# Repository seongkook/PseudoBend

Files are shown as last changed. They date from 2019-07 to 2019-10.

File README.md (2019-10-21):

# PseudoBend

PseudoBend paper is available at here: https://dl.acm.org/citation.cfm?id=3347941

See Video Preview: https://www.youtube.com/watch?v=w7GSAcuDjo4&feature=youtu.be

PseudoBend is a haptic feedback technique that uses grain vibrations to create illusions of stretching, bending, and twisting on a rigid device. Details of PseudoBend will be publised as a paper at ACM UIST 2019.

This repository contains resources required to replicate PseudoBend, including 3D models to print handles, schematic and firmware for signal generation circuit, and PseudoBend software.  

To build the system, you may need the following parts, in addition to the 3D-printed handles. These are the parts used in the implementation in the paper, but you can use alternate parts with similar characteristics.

* Sensor: ATI Nano25 6-DOF Force/Torque Sensor (https://www.ati-ia.com/products/ft/ft_models.aspx?id=Nano25)
* Micro Controller: Teensy 3.6 (https://www.sparkfun.com/products/14057)
* Actuator: Haptuator BM2C (http://tactilelabs.com/wp-content/uploads/2016/06/Haptuator-BMXC-series-v1.1.pdf)
* Amplifier: TDA7297 Audio Amplifier (https://www.amazon.com/DROK-TDA7297-15W-Amplifier-Component/dp/B00C4MT274)

The complete device looks like the picture below, with a force/torque sensor installed in between the two handles.
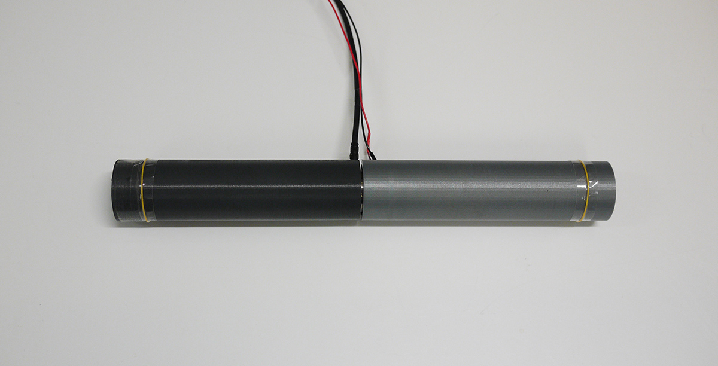
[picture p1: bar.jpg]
Device Image


Nano25 sensor connects the two handles. Three M3 screws connects each handle and the sensor.  
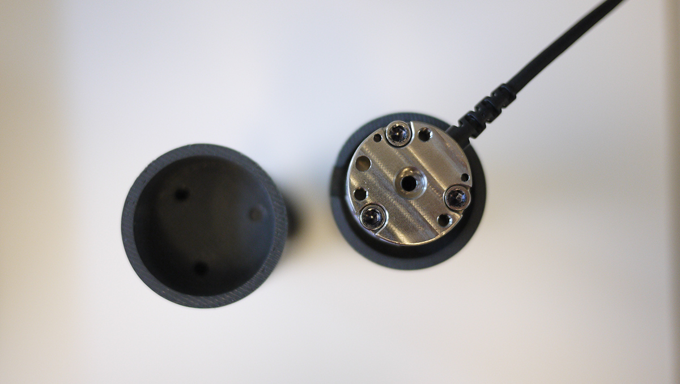
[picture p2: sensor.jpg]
Sensor Image


Teensy 3.6 board generates the vibration signal using its DAC pin. TDA7297 amplifies the signal generated by the Teensy board.  
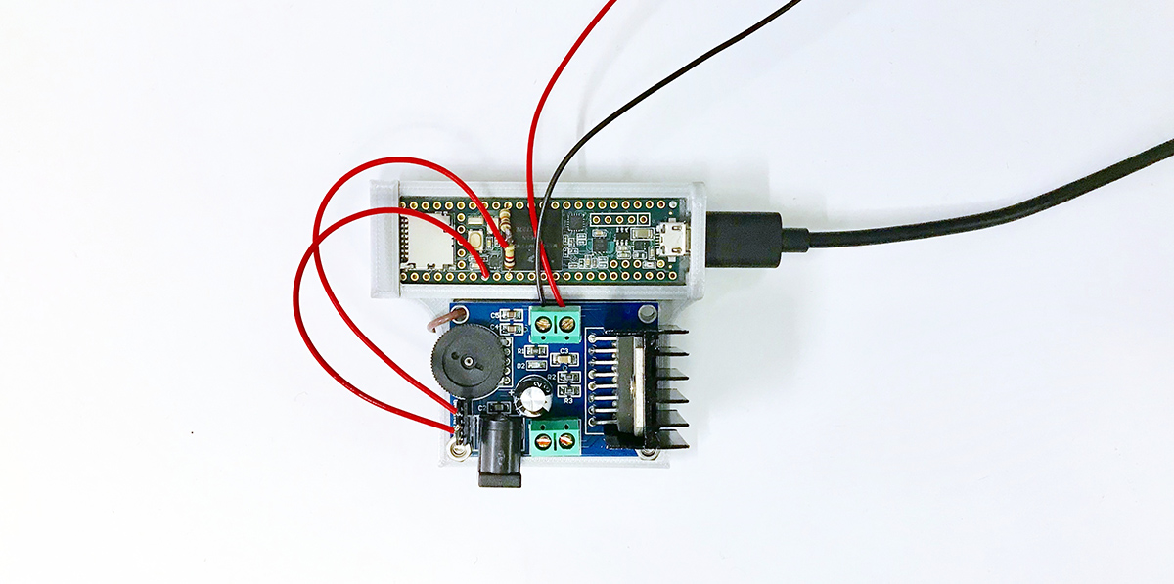
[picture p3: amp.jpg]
Amplifier Image


If you have any questions, please send an email to seongkook@virginia.edu

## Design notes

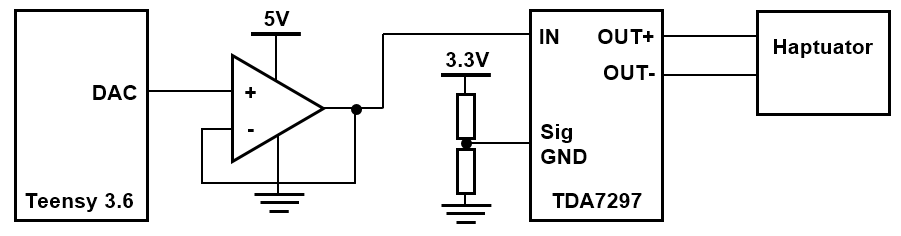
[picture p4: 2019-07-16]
Signal Generator/Circuit Diagram/Drive Circuit.PNG

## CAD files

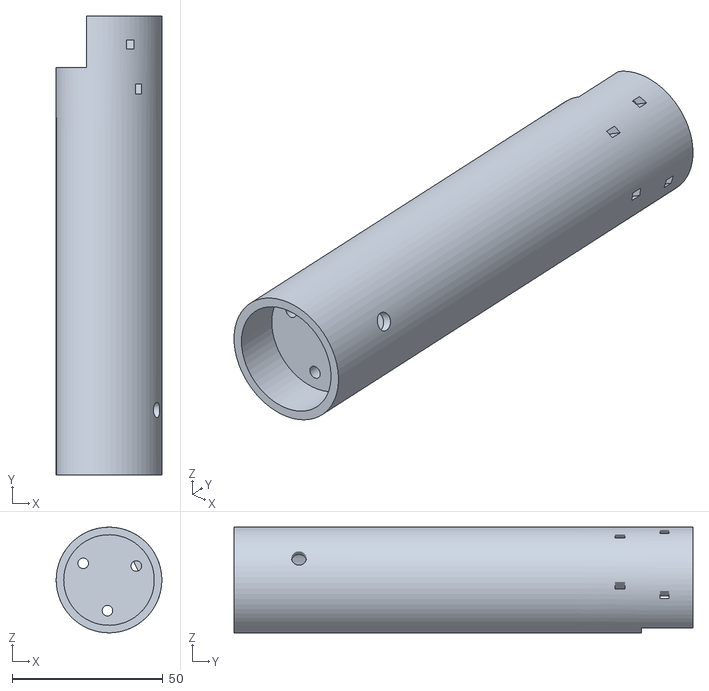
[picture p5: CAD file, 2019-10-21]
3D models/Handle_ActuatorSide_EasyAccess.stl
35.0 x 152.0 x 35.0

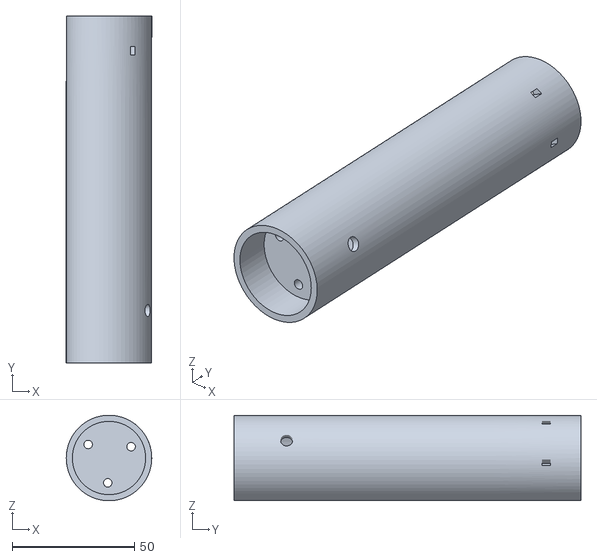
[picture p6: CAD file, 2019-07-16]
3D models/Handle_ActuatorSide.stl
35.0 x 142.0 x 35.0

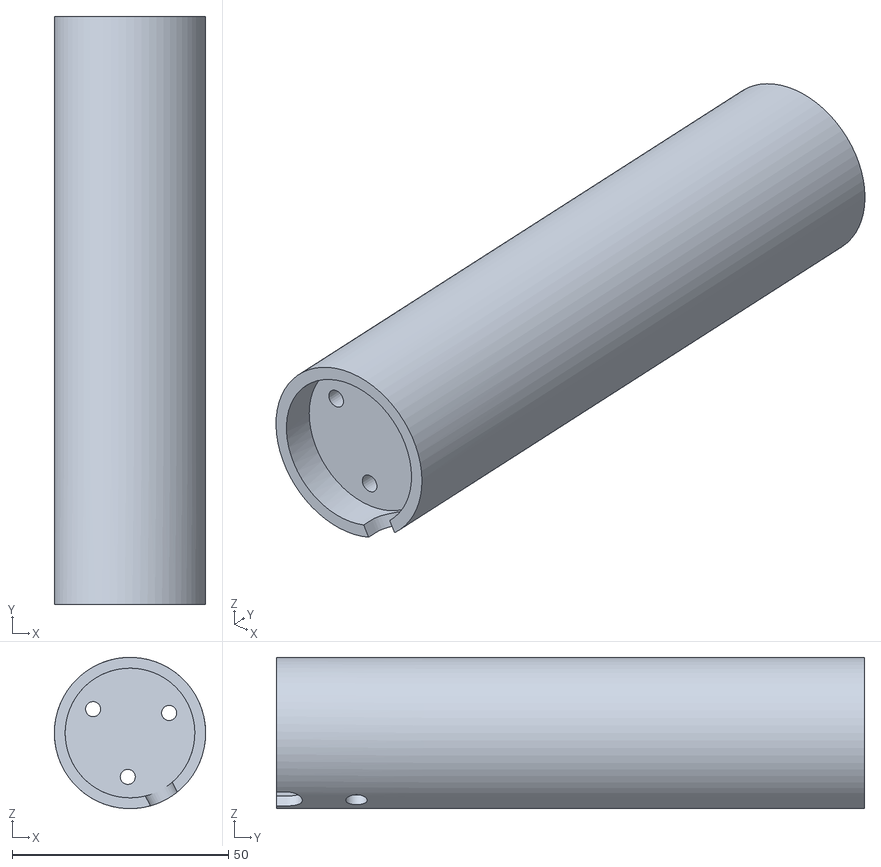
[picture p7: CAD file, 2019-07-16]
3D models/Handle_SensorSide.stl
35.0 x 136.0 x 35.0

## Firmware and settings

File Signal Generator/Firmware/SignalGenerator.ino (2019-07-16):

float twopi = 3.14159 * 2;
int sampleInt = 80;
elapsedMicros usec = 0;

float samples[] {0, 0.10394775, 0.205601561, 0.303866711, 0.397698051, 0.486111111, 0.568192411, 0.643108861, 0.710116167, 0.768566145, 0.817912881, 0.85771768, 0.887652749, 0.907503607, 0.917170192, 0.916666667, 0.906119949, 0.885766994, 0.855950865, 0.817115659, 0.769800359, 0.714631678, 0.652316013, 0.583630584, 0.509413885, 0.430555556, 0.347985795, 0.262664445, 0.175569872, 0.087687766, 1.02E-16, -0.086526339, -0.170949612, -0.252363879, -0.32990861, -0.402777778, -0.470228202, -0.531587093, -0.586258696, -0.633729979, -0.673575314, -0.705460103, -0.729143329, -0.744479007, -0.751416543, -0.75, -0.7403663, -0.722742394, -0.697441445, -0.664858083, -0.625462792, -0.579795513, -0.528458543, -0.472108817, -0.411449677, -0.347222222, -0.280196354, -0.211161613, -0.140917924, -0.070266356, -1.63E-16, 0.069104928, 0.136297664, 0.200861046, 0.26211917, 0.319444444, 0.372263993, 0.420065325, 0.462401225, 0.498893813, 0.529237747, 0.553202527, 0.57063391, 0.581454407, 0.585662894, 0.583333333, 0.574612651, 0.559717794, 0.538932026, 0.512600507, 0.481125224, 0.444959347, 0.404601072, 0.360587049, 0.313485468, 0.263888889, 0.212406914, 0.15965878, 0.106265975, 0.052844945, 1.84E-16, -0.051683518, -0.101645716, -0.149358214, -0.194329729, -0.236111111, -0.274299784, -0.308543557, -0.338543754, -0.364057647, -0.384900179, -0.400944951, -0.41212449, -0.418429807, -0.419909245, -0.416666667, -0.408859001, -0.396693194, -0.380422607, -0.360342931, -0.336787657, -0.310123181, -0.280743601, -0.249065281, -0.215521259, -0.180555556, -0.144617473, -0.108155948, -0.071614027, -0.035423535, -1.63E-16, 0.034262107, 0.066993767, 0.097855382, 0.126540289, 0.152777778, 0.176335576, 0.19702179, 0.214686283, 0.229221482, 0.240562612, 0.248687375, 0.253615071, 0.255405207, 0.254155595, 0.25, 0.243105352, 0.233668594, 0.221913187, 0.208085354, 0.19245009, 0.175287015, 0.15688613, 0.137543514, 0.11755705, 0.097222222, 0.076828033, 0.056653116, 0.036962078, 0.018002124, 1.02E-16, -0.016840697, -0.032341819, -0.046352549, -0.058750848, -0.069444444, -0.078371367, -0.085500022, -0.090828812, -0.094385316, -0.096225045, -0.096429798, -0.095105652, -0.092380607, -0.088401946, -0.083333333, -0.077351703, -0.070643993, -0.063403768, -0.055827778, -0.048112522, -0.04045085, -0.033028659, -0.026021746, -0.019592842, -0.013888889, -0.009038592, -0.005150283, -0.00231013, -0.000580714};
float BOsample[] {0, 0.104528463267653, 0.207911690817759, 0.309016994374947, 0.406736643075800, 0.500000000000000, 0.587785252292473, 0.669130606358858, 0.743144825477394, 0.809016994374948, 0.866025403784439, 0.913545457642601, 0.951056516295154, 0.978147600733806, 0.994521895368273, 1, 0.994521895368273, 0.978147600733806, 0.951056516295154, 0.913545457642601, 0.866025403784439, 0.809016994374948, 0.743144825477394, 0.669130606358858, 0.587785252292473, 0.500000000000000, 0.406736643075800, 0.309016994374948, 0.207911690817759, 0.104528463267654, 1.22464679914735e-16, -0.104528463267654, -0.207911690817760, -0.309016994374947, -0.406736643075800, -0.500000000000000, -0.587785252292473, -0.669130606358858, -0.743144825477394, -0.809016994374947, -0.866025403784439, -0.913545457642601, -0.951056516295154, -0.978147600733806, -0.994521895368273, -1, -0.994521895368273, -0.978147600733806, -0.951056516295154, -0.913545457642601, -0.866025403784439, -0.809016994374948, -0.743144825477395, -0.669130606358858, -0.587785252292473, -0.500000000000000, -0.406736643075800, -0.309016994374948, -0.207911690817760, -0.104528463267653, 0};

int phase = 0;
int BO_phase = 0;
boolean play = false;
boolean playBO = false;
int BO_TimeOut = 5000;

int gain = 512;
int offset = 512;

void setup() {
  analogWriteResolution(10);
}

void loop()
{
  if (Serial.available())
  {
    char inChar = (char)Serial.read();
    Serial.println(inChar);
    
    if (inChar == 'a')  // Grain vibration
    {
      usec = 0;
      play = true;
      phase = 0;
    }
    else if (inChar == 'b') // Bottom out
    {
      usec = 0;
      playBO = true;
      phase = 0;
    }
    else if (inChar == 'p')
    {
      gain =  gain + 100;
      Serial.println(gain);
    }
    else if (inChar == 'l')
    {
      gain =  gain - 100;
      Serial.println(gain);
    }
    else if (inChar == 'o')
    {
      offset =  offset + 100;
      Serial.println(offset);
    }
    else if (inChar == 'k')
    {
      offset =  offset - 100;
      Serial.println(offset);
    }
  }
  if (play)
  {
    if (usec > sampleInt)
    {
      analogWrite(A21, (int)(samples[phase] * gain + offset));
      usec = 0;
      if (phase < 180)
      {
        phase ++;
      }
      else
      {
        play = false;
        phase = 0;
      }
    }
  }
  if(playBO)
  {
    if (usec > BO_TimeOut)
    {
      usec = 0;
      switch(BO_phase)
      {
        case 0:
          analogWrite(A21, (int)(1 * gain + offset));
          BO_phase = 1;
        break;
        case 1:
          analogWrite(A21, (int)(-1 * gain + offset));
          BO_phase = 2;
        break;
        case 2:
          analogWrite(A21, (int)(1 * gain + offset));
          BO_phase = 3;
        break;
        case 3:
          analogWrite(A21, (int)(-1 * gain + offset));
          BO_phase = 4;
        break;        
        case 4:
          analogWrite(A21, (int)(offset));
          BO_phase = 0;
          playBO = false;
        break;
      }
    }
  }  
}
